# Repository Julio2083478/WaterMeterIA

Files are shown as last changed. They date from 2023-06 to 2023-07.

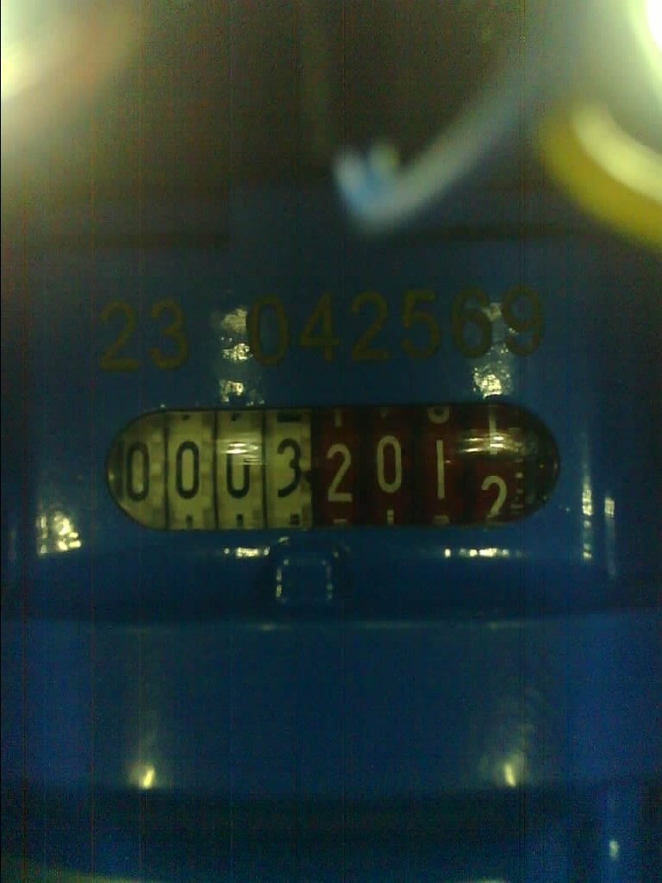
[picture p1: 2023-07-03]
Software/Interfaz/inferencias/1_7_2023_9.jpg

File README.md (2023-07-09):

# DISEÑO DE UN SISTEMA DIGITAL PARA LA LECTURA DE CONTADORES DE AGUA POR MEDIO DE CÁMARAS E IA. 

<p align="center">
  
</p>

## Descripción del sistema.
<p align="justify">
La toma de datos de los medidores es realizada manualmente por las empresas prestadoras de servicios, que van casa por casa registrando el consumo mensual de las mismas, lo que implica que el usuario no pueda llevar un seguimiento detallado de su consumo, supone errores humanos, baja eficiencia, baja efectividad, susceptibilidad a factores ambientales y costos adicionales por la mano de obra requerida. Esto lleva a la necesidad de crear sistemas y/o elementos que automaticen o digitalicen el proceso de recolección de datos en los medidores y faciliten al usuario el seguimiento de su consumo a lo largo del mes.
</p>
<p align="justify">
La inclusión de instrumentos inteligentes debe ser clave, ya que brindan al usuario la posibilidad de llevar un registro detallado del uso del servicio para así poder identificar malos hábitos de consumo, fugas en las tuberías, posible deterioro de estas, desgaste de los sellos o malos empalmes que generan consumos fantasmas, para así tomar las acciones necesarias en pro de evitar sobrecostos generados. Este proyecto pretende implementar un módulo o estructura de fácil acople para medidores de agua convencionales, por medio del cual se capturarán imágenes que serán enviadas inalámbricamente para su posterior análisis y digitalización por medio de IA. 
</p>

## Enlace de la base de datos para segmentar.

* https://app.roboflow.com/ds/DAJvCus5p3?key=saQ0dXVDxN

## Enlace de la base de datos para detección. 

* Para la YoloV8: https://app.roboflow.com/ds/EEVCR4GifU?key=4THAoHTpj3
* Para Detectron: https://app.roboflow.com/ds/PTGveqEZnr?key=orbd7gfs7z

## Instrucciones de uso. 

### Instructivo del Hardware.

<p align="justify">
1. Para ajustar el contador de agua modelo R200 a la estructura, inicie aflojando levemente las tuercas de los extremos, luego coloque el cuerpo principal asegurándose que los orificios en forma de "U" encajen correctamente a cada extremo del tubo del contador, una vez en su lugar finalice apretando nuevamente las tuercas para asegurar la estructura al contador. Es importante tener en cuenta  que el lente de la cámara debe quedar paralelo al contador para garantizar una captura óptima de las imágenes.
</p>

|  |   |   |
|---|---|---|

### NOTA: 
Verifique el nivel de carga del dispositivo. Esto se puede hacer  a través de los  LED’s indicadores incorporados , si todos los LED’s están encendidos la power bank tiene suficiente carga. En caso contrario asegúrese de recargar las baterías para garantizar que el dispositivo esté listo para su uso. 

### Instructivo uso del servidor.
<p align="justify">
1.Diríjase desde su navegador a la página de filezilla (https://filezilla-project.org/) y descargue FileZilla Server.
</p>

<p align="justify">
2.Abra FileZilla en su computador, en la sección de Host ingrese "localhost", deje el puerto que aparece por defecto y por último defina la contraseña que desee.
</p>

<p align="justify">
3.Realice la configuración de los usuarios y grupos, en caso de solo haber usuarios individuales asegúrese de conceder acceso a cada uno de ellos a la carpeta donde se guardarán las imágenes (permisos de escritura y lectura).
</p>

<p align="justify">
4.Verifique que el cortafuegos de su computador permita a filezilla realizar solicitudes por el puerto asignado (puerto 21 por defecto), para más información revise la documentación de Filezilla en la página oficial.
</p>

### Instructivo de la interfaz de usuario.
<p align="justify">
1. Busque la aplicación "Water Meter IA" y dele doble click.
</p>

<p align="center">
  
</p>

<p align="justify">
2. Se mostrará una pestaña de inicio como la siguiente.
</p>
   
<p align="center">
  
</p>

<p align="justify">
3. En la pestaña Ref Contadores encontrará la información general de los usuarios.
</p>

<p align="center">
  
</p>

<p align="justify">
4. En la pestaña medición diaria se presenta la gráfica del consumo diario.
</p>

<p align="center">
  
</p>

<p align="justify">
5. En la pestaña medición semanal se presenta la gráfica del consumo semanal.
</p>

<p align="center">
  
</p>

<p align="justify">
6. En la pestaña medición mensual se presenta la gráfica del consumo mensual.
</p>

<p align="center">
  
</p>

<p align="justify">
7. En la pestaña medición anual se presenta la gráfica del consumo anual.
</p>

<p align="center">
  
</p>

<p align="justify">
8. En la pestaña visualización se observará la última inferencia realizada.
</p>

<p align="center">
  
</p>

## Contribución.
<p align="justify">
Este proyecto se encuentra en constante evolución, por lo que cualquier contribución será bienvenida. Si desea contribuir, por favor envíe un pull request o contacte al equipo de desarrollo.
</p>

## Contacto.

* KATHERINE PAOLA PARRA TARAZONA. katherineparratarazona@gmail.com
  
* JULIO ANDRÉS SÁNCHEZ ABELLO. jasanchezabe@gmail.com

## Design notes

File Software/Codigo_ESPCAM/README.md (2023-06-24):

# Contenido Codigo para toma de datos
Dentro de la carpeta actual, se encuentra el codico de la ESP32 - Cam para almacenar las imagenes en la SD o enviarlas al servidor y borrarlas.

## Tiempo para captura:
El tiempo por defecto esta en **3 horas** 

## Credenciales de servidor:
Es sumamente importante **actualizar las credenciales** en caso de cambiar de red LAN

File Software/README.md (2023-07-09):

# Componentes de software
En esta carpeta se encuentran todos los códigos desarrollados para el funcionamiento de este proyecto, los cuales incluyen:

1) Código para toma y transferencia de datos con la ESP32-Cam.
2) Códigos de entrenamiento del modelo de segmentación y de los modelos de detección.
3) Código de la interfaz de usuario.

## Código de la ESP32-Cam.
En este apartado se encuentra el código de la ESP32-Cam, donde se captura una imagen del contador de agua cada tres horas. Además, realiza el proceso de conexión al servidor local FTP para enviar las imágenes capturadas,  en caso de no estar disponible se guardan en la tarjeta SD hasta indicar disponibilidad para ser enviadas y eliminadas de la memoria.

## Códigos de entrenamiento
En esta carpeta se encuentran los códigos realizados para el entrenamiento y validación con YOLOv8m en segmentación, YOLOv8m y Detectron2 para detección, con el fin de realizar una comparativa de rendimiento entre estos dos últimos, cada modelo se encuentra con su respectivo código en google colab donde fueron ejecutados y se  observan las métricas de rendimiento obtenidas en cada caso.

## Código de la interfaz
En esta carpeta se encuentran todos los archivos y los recursos utilizados para el funcionamiento de la interfaz desarrollada en Qt Designer. Se incluyen todos los elementos visuales como iconos e imágenes que se muestran en la interfaz, así como los códigos generados para su correcto funcionamiento y despliegue.
******

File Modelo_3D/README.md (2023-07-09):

# Contenido Modelo 3D
Dentro de esta carpeta se encuentran todos los archivos relacionados con el diseño de las estructuras en 3D realizadas para este proyecto, este diseño se realizó para contadores de agua modelo R200.

## Archivos_STL:
En la carpeta **Archivos_STL**, encontrará los archivos utilizados para la impresión 3D de cada una de las piezas. Se recomienda tener en cuenta que la impresión se realizó con el material PLA de 0.6 mm.

## Archivos_piezas:
La carpeta **Archivos_piezas**, contiene todos los archivos correspondientes a las diferentes piezas empleadas en el diseño. Los archivos allí almacenados fueron desarrollados mediante el software de diseño CAD SolidWorks.

## Planos:
En la carpeta **Planos**, se encuentran los archivos correspondientes a los planos generados para cada una de las piezas diseñadas. Cada plano contiene una vista isométrica y, adicionalmente tres vistas de la pieza, en las que es posible visualizar las dimensiones exactas de cada una, con el objetivo de facilitar su interpretación. 

# Cómo usarlo:
Descargue el repositorio en su computador y siga las instrucciones expuestas a continuación.

## Para editar las piezas:
+ Para _**visualizar**_ o _**editar**_ las piezas de este proyecto:

  **1.** Ingrese a la carpeta **"Modelo_3D"** contenida en el repositorio.

  **2.** Diríjase a la carpeta **"Archivos_piezas"**.

  **3.** Escoja el archivo que desee visualizar y ábralo con SolidWorks.

  **4.** Empiece a editar la pieza a su gusto.

  **5.** Guarde los cambios realizados.

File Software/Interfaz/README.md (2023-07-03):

# INTERFAZ
Esta carpeta contiene todos los archivos necesarios para la correcta ejecución la interfaz de la aplicación **WATER METER**.
## GUIA DE USO
1. Para la correcta ejecución de la interfaz se recomienda hacer git clone al repositorio.
2. Descargar los modelos de aprendizaje profundo complementarios a la aplicación.

### Modelo de segmentación y detección: [LINK MODELOS](https://drive.google.com/drive/folders/1-WFLHzTR1dka6NE3B_RX2ybUrJGjjaGC?usp=sharing)

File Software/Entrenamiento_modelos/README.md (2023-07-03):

# Entrenamiento de modelos
En este apartado se encuentran los codigos que fueron ejecutados para el entrenamiento de los modelos de segmentación y detección.
## Aportes
En caso de contar con un dataset más robusto para el entrenamiento de los modelos, lo invito a compartirlo con la herramienta de roboflow para realizar actualizaciones al proyecto y mejorar su desempeño.

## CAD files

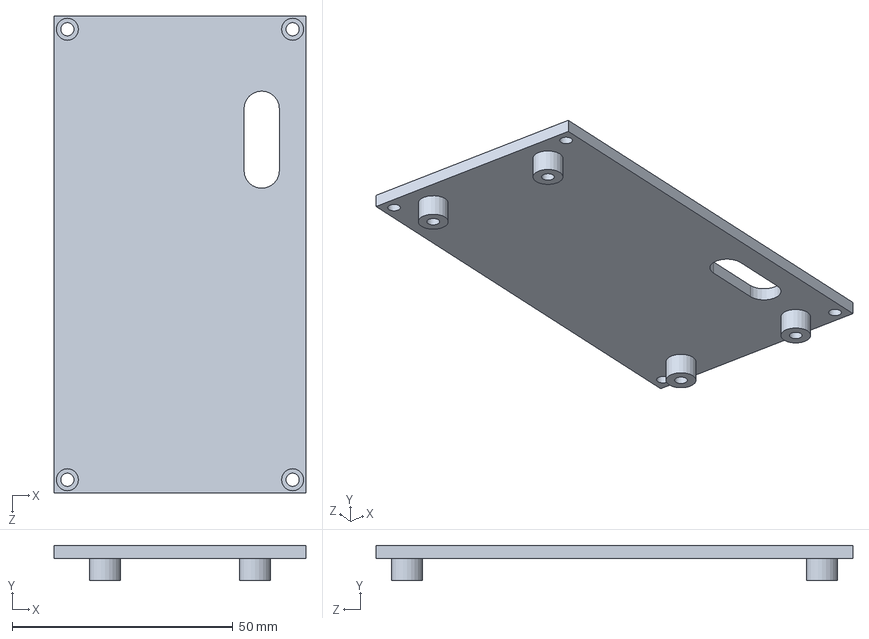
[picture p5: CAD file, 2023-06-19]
Modelo_3D/Archivos_piezas/Estructura_Tapa_banco_de_baterías.SLDPRT
57.0 x 8.00 x 108.0 mm

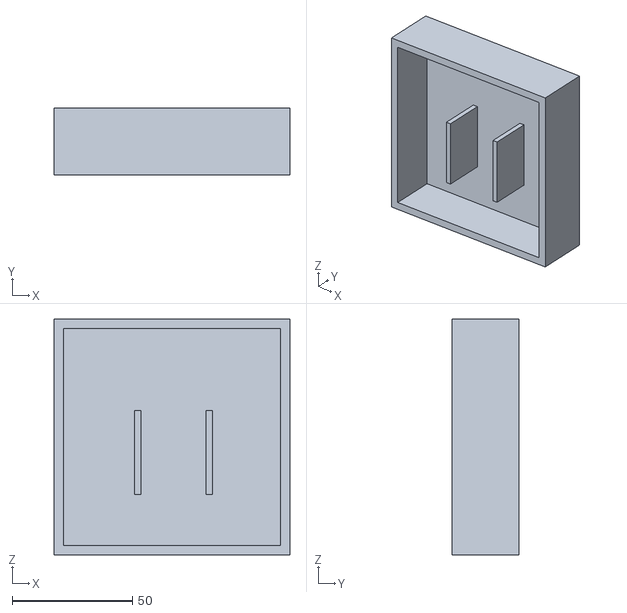
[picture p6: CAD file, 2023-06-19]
Modelo_3D/Archivos_STL/Estructura_Tapa.STL
98.2 x 28.0 x 98.2

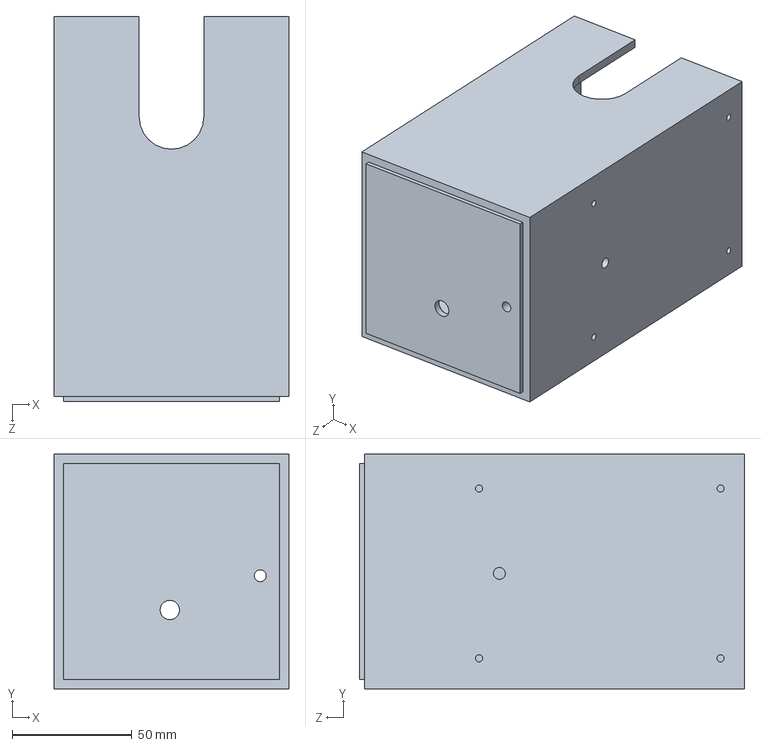
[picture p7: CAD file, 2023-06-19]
Modelo_3D/Archivos_piezas/Estructura_Cuerpo.SLDPRT
98.2 x 98.2 x 161.0 mm

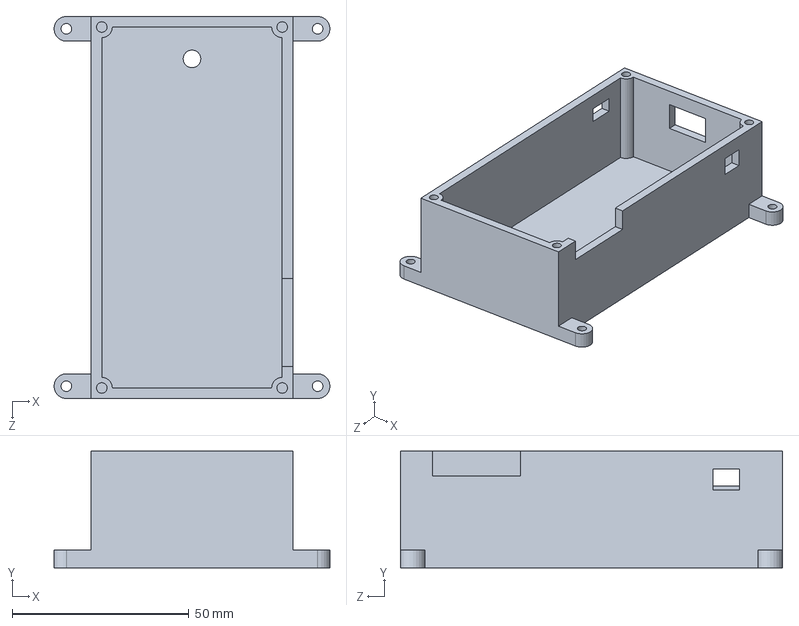
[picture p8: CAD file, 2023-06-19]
Modelo_3D/Archivos_piezas/Estructura_Banco_de_baterías.SLDPRT
78.0 x 33.0 x 108.0 mm

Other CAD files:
Modelo_3D/Archivos_STL/Estructura_Cuerpo.STL
Modelo_3D/Archivos_STL/Estructura_Banco_de_baterías.STL
Modelo_3D/Archivos_piezas/Estructura_Tapa.SLDPRT
Modelo_3D/Archivos_STL/Estructura_Tapa_banco_de_baterías.STL

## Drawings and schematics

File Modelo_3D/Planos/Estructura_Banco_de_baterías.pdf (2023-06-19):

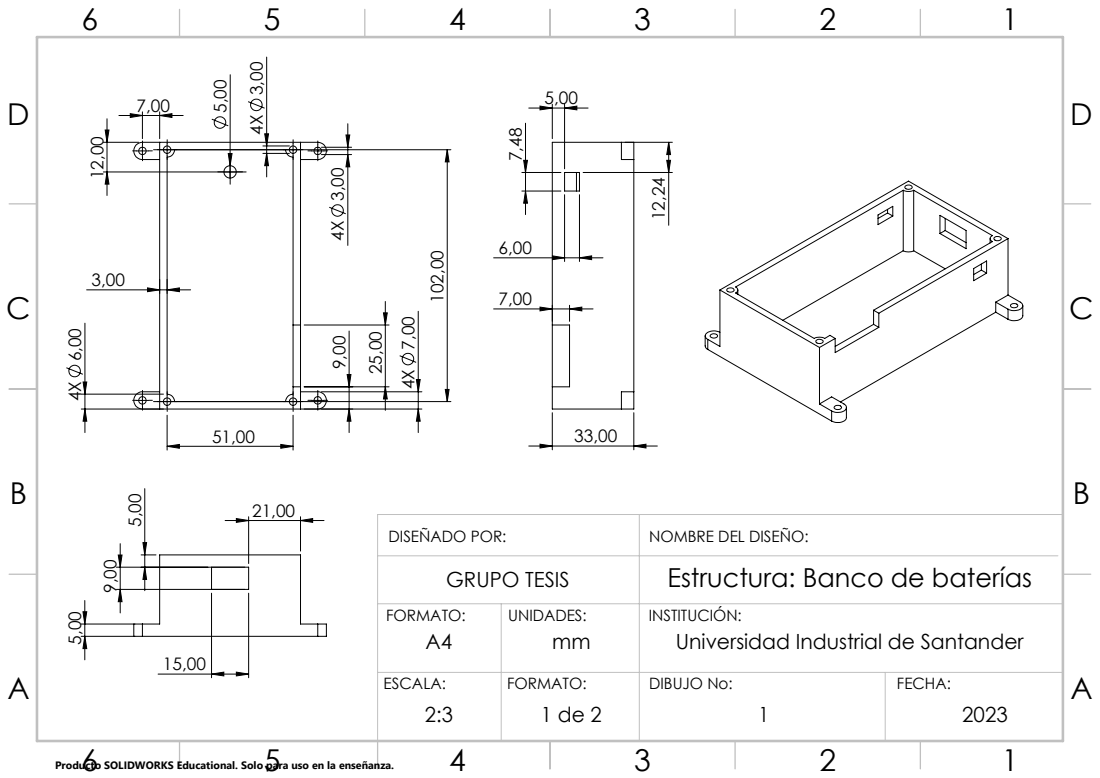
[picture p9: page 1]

DISEÑADO POR: GRUPO TESIS | NOMBRE DEL DISEÑO: Estructura: Banco de baterías

Producto SOLIDWORKS Educational. Solo para uso en la enseñanza.

FORMATO: A4 | UNIDADES: mm | INSTITUCIÓN: Universidad Industrial de Santander

ESCALA: 2:3 | FORMATO: 1 de 2 | DIBUJO No: 1 | FECHA: 2023

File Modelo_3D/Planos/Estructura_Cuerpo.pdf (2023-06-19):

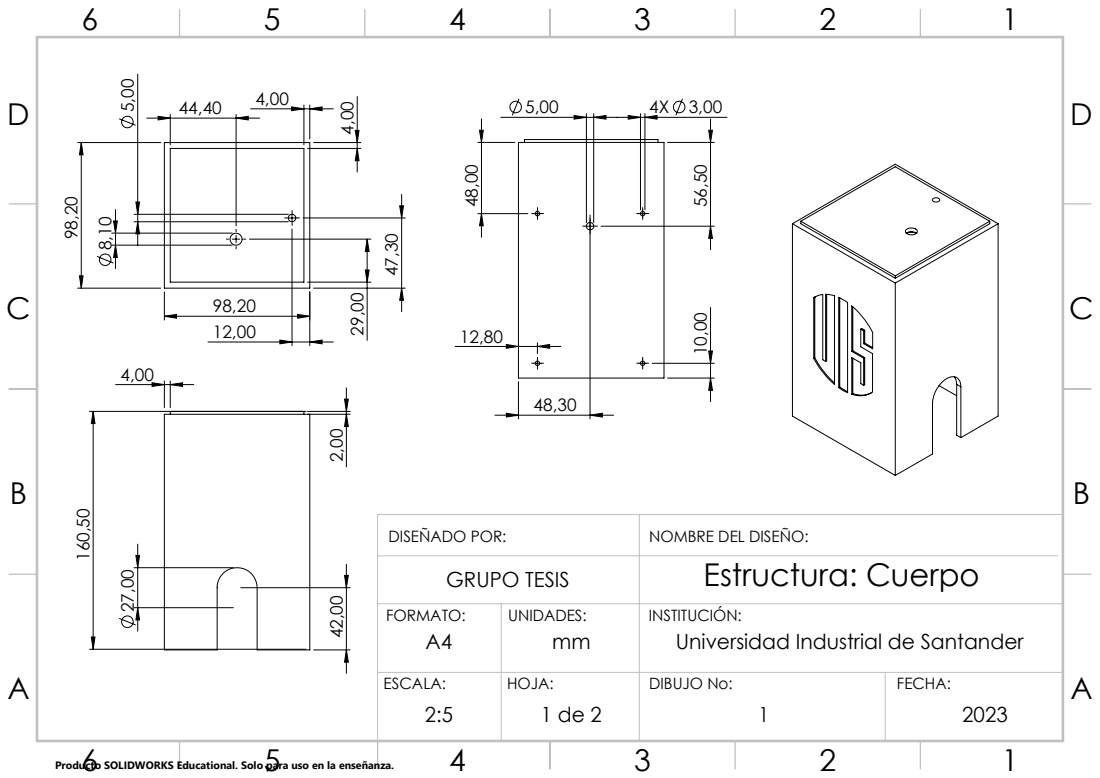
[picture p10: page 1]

DISEÑADO POR: GRUPO TESIS | NOMBRE DEL DISEÑO: Estructura: Cuerpo

FORMATO: A4 | UNIDADES: mm | INSTITUCIÓN: Universidad Industrial de Santander

Producto SOLIDWORKS Educational. Solo para uso en la enseñanza.

ESCALA: 2:5 | HOJA: 1 de 2 | DIBUJO No: 1 | FECHA: 2023

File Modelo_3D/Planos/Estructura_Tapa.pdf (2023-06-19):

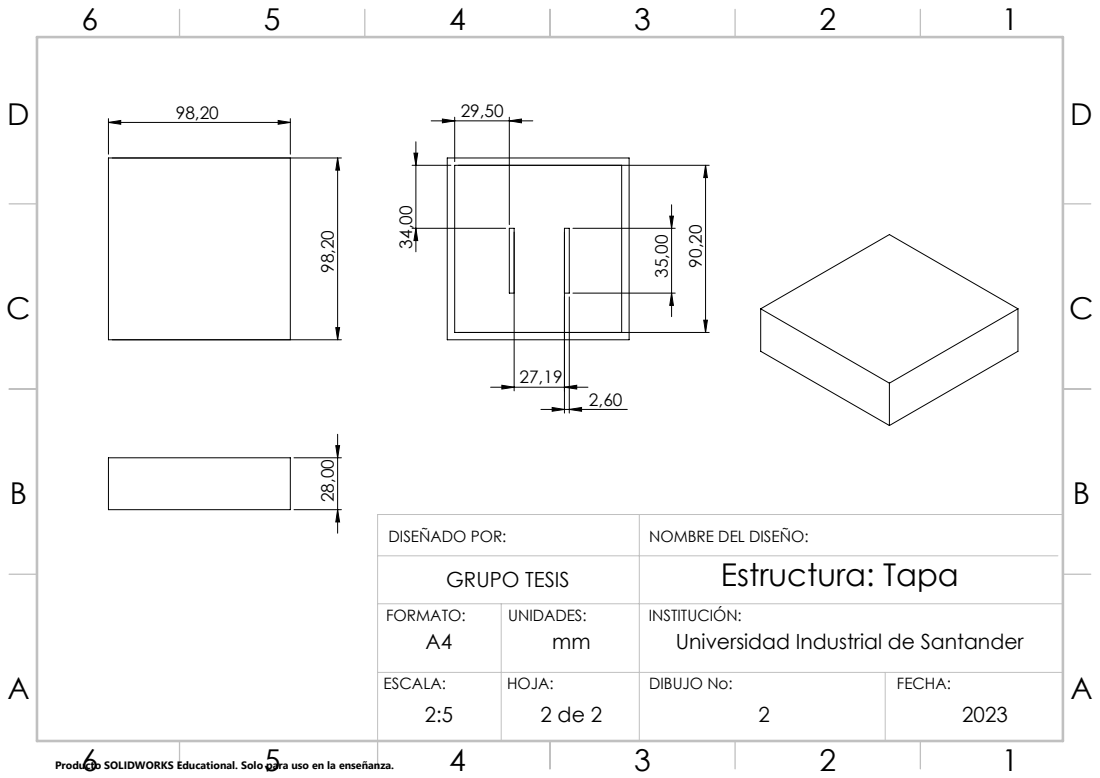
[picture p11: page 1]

DISEÑADO POR: GRUPO TESIS | NOMBRE DEL DISEÑO: Estructura: Tapa

FORMATO: A4 | UNIDADES: mm | INSTITUCIÓN: Universidad Industrial de Santander

Producto SOLIDWORKS Educational. Solo para uso en la enseñanza.

ESCALA: 2:5 | HOJA: 2 de 2 | DIBUJO No: 2 | FECHA: 2023

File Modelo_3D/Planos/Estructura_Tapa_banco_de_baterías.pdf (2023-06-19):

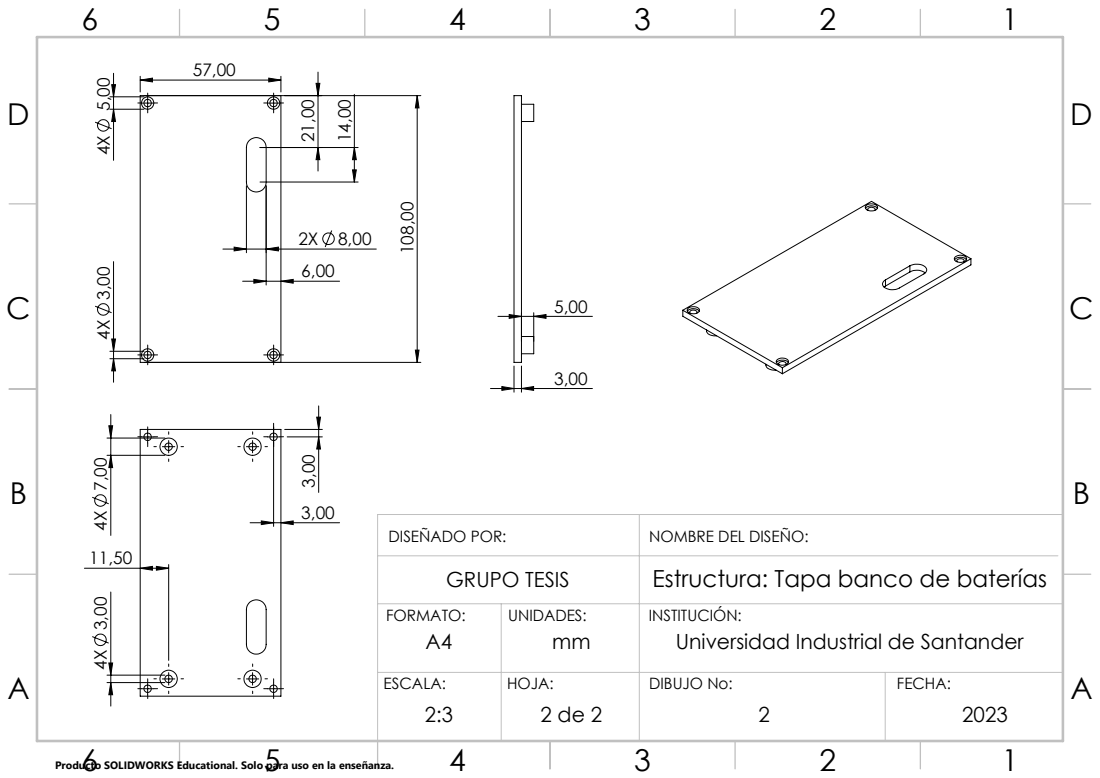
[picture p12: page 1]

DISEÑADO POR: GRUPO TESIS | NOMBRE DEL DISEÑO: Estructura: Tapa banco de baterías

FORMATO: A4 | UNIDADES: mm | INSTITUCIÓN: Universidad Industrial de Santander

Producto SOLIDWORKS Educational. Solo para uso en la enseñanza.

ESCALA: 2:3 | HOJA: 2 de 2 | DIBUJO No: 2 | FECHA: 2023

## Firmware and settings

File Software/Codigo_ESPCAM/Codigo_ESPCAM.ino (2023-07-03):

#include "esp_camera.h"
#include "soc/soc.h"
#include "soc/rtc_cntl_reg.h"
#include "driver/rtc_io.h"
#include <WiFi.h>
#include <WiFiClient.h>
#include "ESP32_FTPClient.h"
#include <NTPClient.h>
#include <WiFiUdp.h>
#include "time.h"
#include "FS.h"
#include "SD_MMC.h"

char* ftp_server = "192.168.1.11";  // Dirección IP del servidor FTP
char* ftp_user = "hola";  // Nombre de usuario del servidor FTP
char* ftp_pass = "2181";  // Contraseña del servidor FTP
char* ftp_path = "/";  // Ruta en el servidor FTP

const char* WIFI_SSID = "******";  // Nombre de la red Wi-Fi
const char* WIFI_PASS = "*******";  // Contraseña de la red Wi-Fi

WiFiUDP ntpUDP;
NTPClient timeClient(ntpUDP, "pool.ntp.org", (-3600*5), 60000);// Cliente NTP para obtener la hora actual
ESP32_FTPClient ftp(ftp_server, ftp_user, ftp_pass, 6000, 2);// Cliente FTP para la conexión y transferencia de archivos

// Definición de pines para el modelo de cámara AI-THINKER
#define PWDN_GPIO_NUM     32
#define RESET_GPIO_NUM    -1
#define XCLK_GPIO_NUM      0
#define SIOD_GPIO_NUM     26
#define SIOC_GPIO_NUM     27
#define Y9_GPIO_NUM       35
#define Y8_GPIO_NUM       34
#define Y7_GPIO_NUM       39
#define Y6_GPIO_NUM       36
#define Y5_GPIO_NUM       21
#define Y4_GPIO_NUM       19
#define Y3_GPIO_NUM       18
#define Y2_GPIO_NUM        5
#define VSYNC_GPIO_NUM    25
#define HREF_GPIO_NUM     23
#define PCLK_GPIO_NUM     22
#define SDMMC_FREQ_DEFAULT 20000000

camera_config_t config;

void setup() {
  WRITE_PERI_REG(RTC_CNTL_BROWN_OUT_REG, 0); // Deshabilitar detector de caídas de voltaje
  Serial.begin(115200);
  pinMode(3, OUTPUT);
  
  

  WiFi.begin(WIFI_SSID, WIFI_PASS);
  Serial.println("Conectando a WiFi...");
  while (WiFi.status() != WL_CONNECTED) {
    delay(500);
    Serial.println("Conectando a WiFi...");
  }

  Serial.println("Dirección IP:");
  Serial.println(WiFi.localIP());
  
  // Configuración de la cámara
  config.ledc_channel = LEDC_CHANNEL_0;
  config.ledc_timer = LEDC_TIMER_0;
  config.pin_d0 = Y2_GPIO_NUM;
  config.pin_d1 = Y3_GPIO_NUM;
  config.pin_d2 = Y4_GPIO_NUM;
  config.pin_d3 = Y5_GPIO_NUM;
  config.pin_d4 = Y6_GPIO_NUM;
  config.pin_d5 = Y7_GPIO_NUM;
  config.pin_d6 = Y8_GPIO_NUM;
  config.pin_d7 = Y9_GPIO_NUM;
  config.pin_xclk = XCLK_GPIO_NUM;
  config.pin_pclk = PCLK_GPIO_NUM;
  config.pin_vsync = VSYNC_GPIO_NUM;
  config.pin_href = HREF_GPIO_NUM;
  config.pin_sscb_sda = SIOD_GPIO_NUM;
  config.pin_sscb_scl = SIOC_GPIO_NUM;
  config.pin_pwdn = PWDN_GPIO_NUM;
  config.pin_reset = RESET_GPIO_NUM;
  config.xclk_freq_hz = 20000000;
  config.pixel_format = PIXFORMAT_JPEG; 
  if (psramFound()) { // Verificar si se encontró una memoria PSRAM
    config.frame_size = FRAMESIZE_UXGA; // Tamaño de fotograma: UXGA (1600x1200)
    config.jpeg_quality = 10; // Calidad de compresión JPEG: 10 
    config.fb_count = 2; // Contador de buffers de frame: 2 (mejor rendimiento)
  } else {
    config.frame_size = FRAMESIZE_XGA; // Tamaño de fotograma: XGA (1024x768)
    config.jpeg_quality = 12; // Calidad de compresión JPEG: 12 
    config.fb_count = 1; // Contador de buffers de frame: 1
  }


  // Inicialización de la tarjeta SD
  if (!SD_MMC.begin()) {
    Serial.println("Fallo al montar la tarjeta SD");
    return;
  }

  // Verificación del tipo de tarjeta SD
  uint8_t cardType = SD_MMC.cardType();// Obtener el tipo de tarjeta SD
  
  if (cardType == CARD_NONE) {
    Serial.println("No se ha detectado una tarjeta SD");
    return;
  }

  delay(1000); // Retardo de 1 segundo
  timeClient.begin(); // Inicializar el cliente NTP
  timeClient.update(); // Obtener la hora actual desde el servidor NTP
  delay(3000); // Retardo de 3 segundos
  Serial.println(timeClient.getFormattedTime()); // Imprimir la hora formateada obtenida del servidor NTP

   digitalWrite(3, HIGH);//Encendido de los leds antes de inicializar la camara para que se acostumbre a esta luz
  // Inicialización de la cámara
  esp_err_t err = esp_camera_init(&config);
  if (err != ESP_OK) {
    Serial.printf("Error al inicializar la cámara: 0x%x", err);
    return;
  }

  delay(10000);//tiempo de espera para que la cámara se ajuste a la luz proporcionada
  
  // Verificación de disponibilidad del servidor FTP y envío de imágenes
  if (ftpAvailable()) {
    ftp.OpenConnection();
    sendImagesToServerAndDelete();
  }

  takeAndSavePhoto();

  esp_deep_sleep(3*3600* 1000000);// Se despierta cada 3 horas para tomar captura 
}

void loop() {
  
}

void takeAndSavePhoto() {
  camera_fb_t* fb = NULL;

  // Capturar imagen con la cámara
  fb = esp_camera_fb_get();

  if (!fb) {
    Serial.println("Fallo al capturar la imagen de la cámara");
    delay(1000);
    ESP.restart();
  }

  // Obtener la fecha y hora actual
  unsigned long epochTime = timeClient.getEpochTime();
  struct tm* ptm = gmtime((time_t*)&epochTime);
  int year = ptm->tm_year + 1900;
  int month = ptm->tm_mon + 1;
  int day = ptm->tm_mday;
  int hour = ptm->tm_hour;
  int minute = ptm->tm_min;
  String dateTime;

  dateTime = String(day) + "_" + String(month) + "_" + String(year) + "_" + String(hour);

  String path = "/" + String(dateTime) + ".jpg";

  Serial.println("Subiendo " + path);

  // Guardar la imagen capturada en la tarjeta SD
  
  fs::FS& fs = SD_MMC;// Seleccionar el sistema de archivos (SD_MMC en este caso)
  Serial.printf("Nombre del archivo de imagen: %s\n", path.c_str());

  File file = fs.open(path.c_str(), FILE_WRITE);
  if (!file) {
    Serial.println("Error al abrir el archivo en modo de escritura");
  } else {
    file.write(fb->buf, fb->len);
    Serial.printf("Archivo guardado en la ruta: %s\n", path.c_str());
  }
  
  file.close(); // Cerrar el archivo
  esp_camera_fb_return(fb); // Liberar el búfer de frame de la cámara
  digitalWrite(3, LOW); //apagado de los leds
  
}

void sendImagesToServerAndDelete() {
  Serial.println("Enviando imágenes al servidor FTP y eliminándolas de la tarjeta SD:");
  
  File root = SD_MMC.open("/"); // Abrir la carpeta raíz en la tarjeta SD
  File file = root.openNextFile(); // Abrir el siguiente archivo en la carpeta raíz

  while (file) {
    if (!file.isDirectory()) {
      String filename = file.name();// Obtener el nombre del archivo
      Serial.println(filename);
      if (filename.endsWith(".jpg")) {// Verificar si el archivo es una imagen JPG
        Serial.println("Subiendo " + filename);
        ftp.InitFile("Type I");
        ftp.NewFile(filename.c_str());

        if (file.size() > 0) {
          uint8_t buf[256];
          size_t len;
          while ((len = file.read(buf, sizeof(buf))) > 0) {
            ftp.WriteData(buf, len);
          }
        }
        // Cerrar el archivo
        ftp.CloseFile();
        file.close();
        
        // Eliminar el archivo de la tarjeta SD
        SD_MMC.remove(filename.c_str());
      }
    }
    
    delay(4000);
    file = root.openNextFile();// Abrir el siguiente archivo en la carpeta raíz
  }

  root.close();
}

bool ftpAvailable() {
  Serial.println("Comprobando disponibilidad del servidor FTP...");
  WiFiClient client;
  
  if (client.connect(ftp_server, 21)) {
    Serial.println("El servidor FTP está disponible");
    client.stop();
    return true;
  } else {
    Serial.println("El servidor FTP no está disponible");
    return false;
  }
}

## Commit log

2023-06-19 Agrego la carpeta correspondiente a los archivos editables de las piezas
    [Estructura_Banco_de_baterías.SLDPRT, Estructura_Cuerpo.SLDPRT, Estructura_Tapa.SLDPRT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]
2023-06-19 Archivos editables de las piezas
    [Estructura_Banco_de_baterías.SLDPRT, Estructura_Cuerpo.SLDPRT, Estructura_Tapa.SLDPRT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]
2023-06-19 Archivos STL de las piezas
    [Estructura_Banco_de_baterías.STL, Estructura_Cuerpo.STL, Estructura_Tapa.STL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]
2023-06-19 Planos de las piezas
2023-06-23 Codigo de la espcam para almacenamiento y envio de imagenes a servidor
2023-06-23 Actualizo Codigo_ESPCAM.ino para captura cada 6 horas
2023-06-29 Update README.md
    instruciones de filezilla
2023-07-02 creacion de carpeta
2023-07-03 Listo para despliegue con encendido de leds Codigo_ESPCAM.ino
2023-07-03 Create README.md
    README.me para la visualización de la pestaña "interfaz"
2023-07-03 Update README.md
    Actualicé la descripción del código de la interfaz
2023-07-03 CARPETA ICONOS
    Añado carpeta de iconos necesaria para la ejecución de la interfaz
2023-07-03 CARPETA ICONOS
    Añado carpeta ICONOS FINAL para la interfaz
2023-07-03 CARPETA INFERENCIAS
    Añado la carpeta en la cual se harán las correspondientes inferencias de las imágenes.
2023-07-03 CARPETA VISUALIZACIÓN
    Añado la carpeta visualización, que será usada en la pestaña "visualizar" desde la interfaz, en ella estará la ultima inferencia con su correspondiente medición
2023-07-03 MAIN.PY
    Añado el main.py (código base para la ejecución de la interfaz),
2023-07-03 ui_INTERFAZMOCKUPFINAL.py
    Añado el código generado de "QtDesigner", que contiene la estética generada de la interfaz.
2023-07-03 INTERFAZMOCKUPFINAL.ui
    Añado el archivo.ui, que permite modificar la interfaz desde la aplicación de "QtDesigner".
2023-07-03 Funcion_inferencia.py
    Añado la función que está encargada de realizar todos los procesos necesarios para inferir los números del contador.
2023-07-03 INSTALADOR DE DEPENDENCIAS
    Añado el instalador de dependencias, el cual instalará todo lo necesario para el correcto funcionamiento de la interfaz.
2023-07-03 registros.csv
    Añado el .csv que contiene los registros realizados mediante la interfaz.
    [registros.csv]
2023-07-03 water_consumption_f.csv
    Añado el .csv que contiene las mediciónes con su correspondiente fecha y hora, será este archivo en el cual se guardará la información luego de la inferencia.
    [water_consumption_f.csv]
2023-07-03 Update README.md
    Modifiqué el readme
2023-07-10 Añado el main.py
    Se modificó para detectar errores
2023-07-11 Archivo.ui para QTDesigner
